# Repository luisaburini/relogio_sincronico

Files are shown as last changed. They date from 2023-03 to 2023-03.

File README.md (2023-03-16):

# Relógio Sincrônico

Instruções para montagem do trabalho de arte "Relógio Sincrônico" da artista Isadora Maia, que esteve na exposição "Mesmo Estando Separados" com a curadoria de Bruna Fernanda, Caio Bonifácio, Érica Burini, Glauce Santos e Lucas Goulart, no Ateliê 397, que fica na Rua Cruzeiro, 802, Barra Funda. 

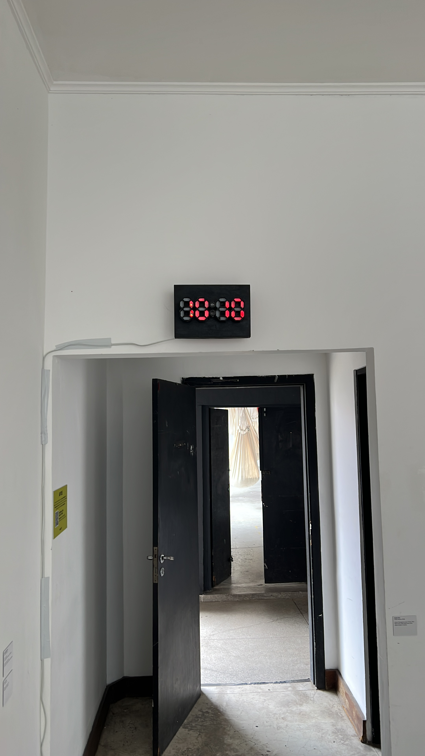
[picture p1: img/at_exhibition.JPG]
At exhibition

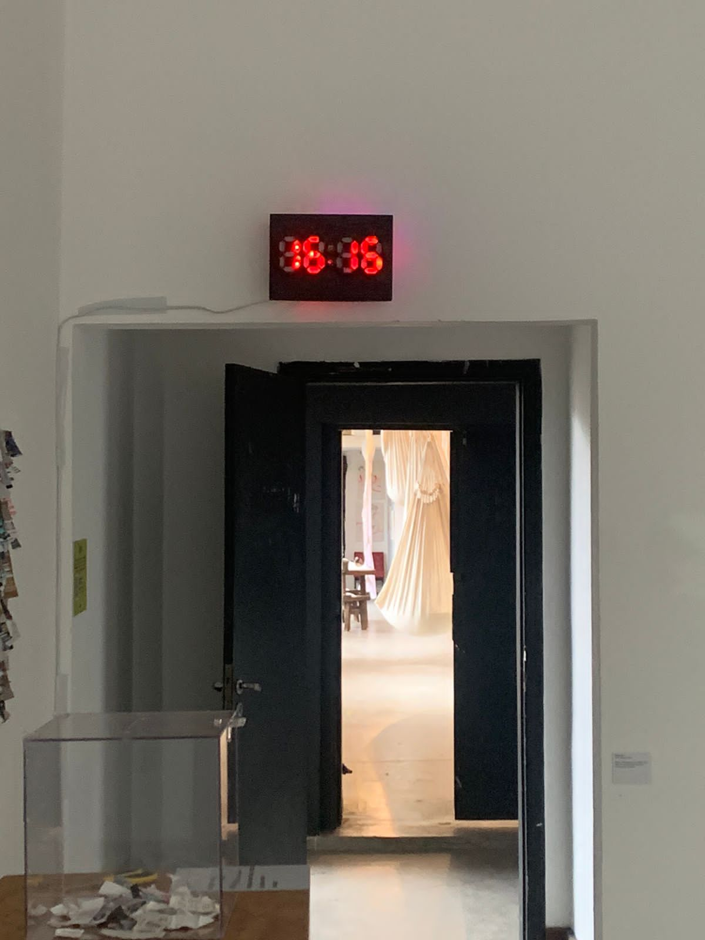
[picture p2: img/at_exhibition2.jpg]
At exhibition


## Materiais

- Arduino UNO R3 ATMEGA328p
- Módulo Real Time Clock DS3231
- Bateria de Lítio Recarregável LI2032 3,6V
- 5 mini protoboards 170 furos
- Jumpers (macho-macho e macho-fêmea)
- Fonte 5V para Arduino
- 5m fita de LEDs WS2811 
- Ferro de solda e estanho 
- Fonte 12V para fita de LEDs
- Caixa de MDF (32x22x5 cm)
- Tinta Spray preto fosco
- Impressão 3D - 28 Difusores para Segmentos
- Impressão 3D - 2 Difusores para Pontos
- Impressão 3D - Traseira
- Impressão 3D - Frente
- Folha de Acetato A3 30x42 cm
- Velcro
- 2 mão francesa 
- Extensão Tripolar de 5m branca 

## Descrição

O trabalho de montagem consistiu em obter uma solução para montar um relógio que exibe a mesma informação ha hora no minuto.
Para concretizar esse relógio, foi usado um Arduino conectado ao módulo RTC para obter a hora, mapear cada dígito em um buffer do tamanho da fita de led que ilumine apenas os trechos que representem o número.
Para exibir os dígitos, foi usado um molde de impressão 3D que forme o desenho do display de 7 segmentos.
A caixa de MDF pintada com tinta spray encapsulou os demais materiais, em especial para esconder os jumpers, protoboard e mostrar as peças feitas por impressão 3D com a fita LED no interior. A folha de acetato e o velcro evitam que as peças internas tenham contato com a parede e, por fim, a mão francesa garante apoio na parede para pendurar.

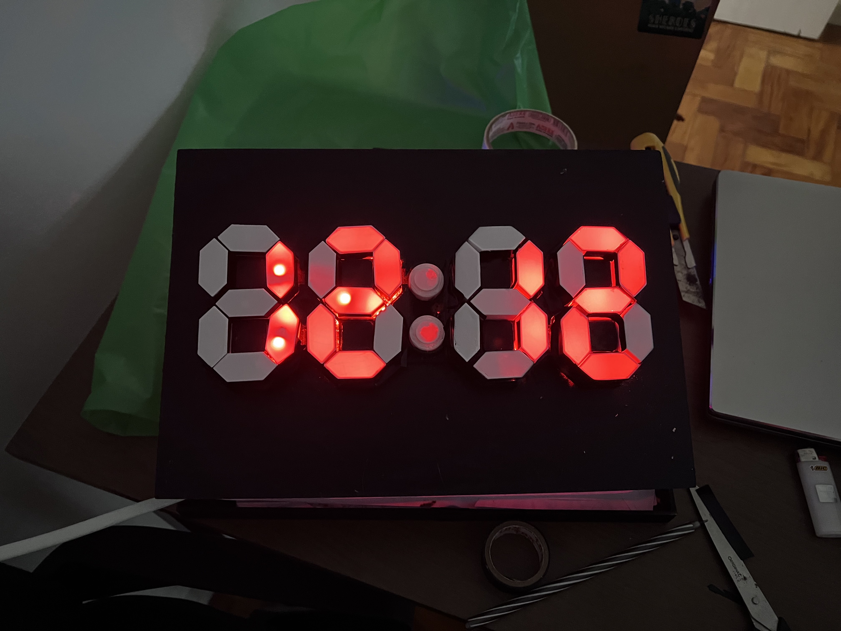
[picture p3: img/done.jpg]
Done!


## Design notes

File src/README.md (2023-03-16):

# Circuito 

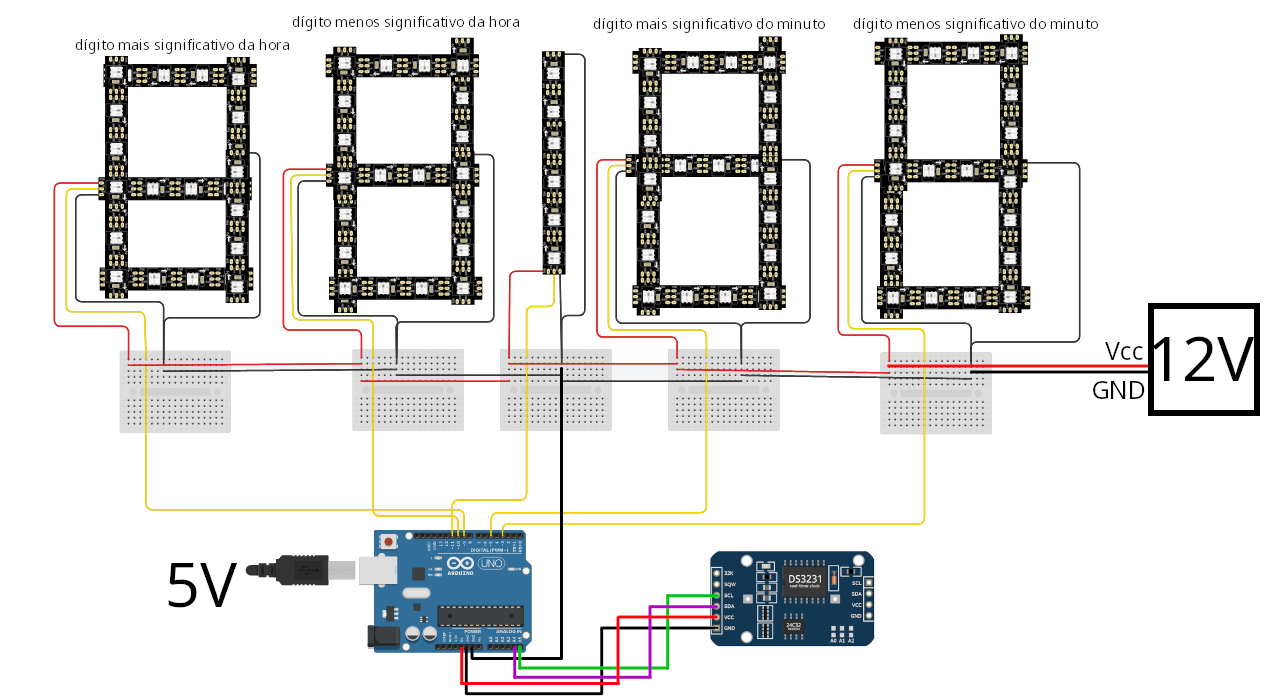
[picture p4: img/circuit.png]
Circuit

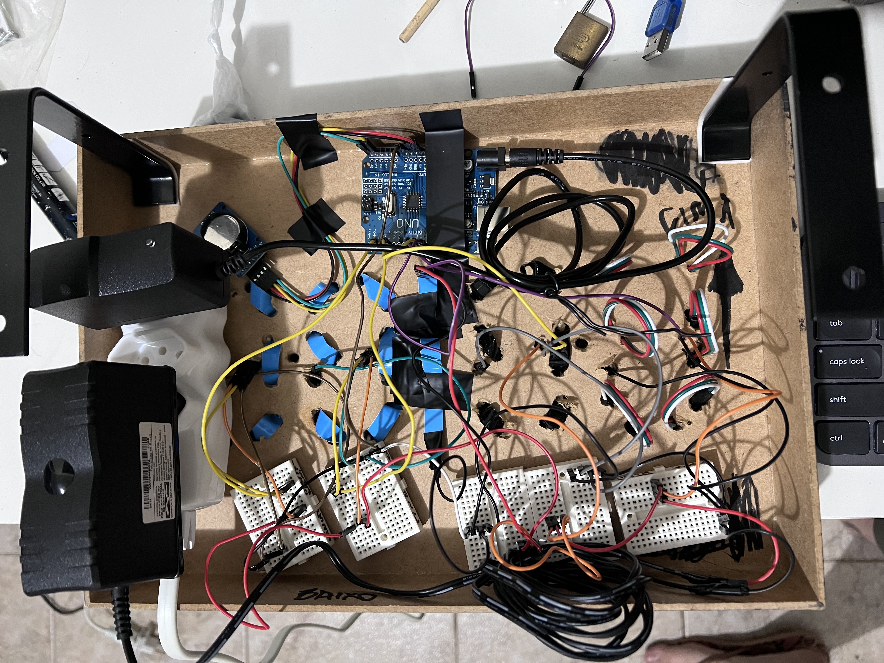
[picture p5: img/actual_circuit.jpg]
Actual Circuit


## RTC 

Foi utilizado o módulo DS3231, com a biblioteca [RTClib](https://adafruit.github.io/RTClib/html/class_r_t_c___d_s3231.html)

| Pino Arduino | Pino RTC |
|:---:|:---:|
| A5 | SCL |
| A4 | SDA |
| 5V | VCC |
| GND | GND |

*Atenção:* Foi utilizado 5V devido a bateria recarregável LI2032 3,6V. Se utilizar uma bateria CR2032 conecte em 3V!

OBS.: A bateria recarregável pode demorar até 2 dias para carregar o suficiente para salvar o dado da data/hora!

## Fita LED

Para conectar as fitas de LED ao Arduino, foi necessário soldar jumpers machos na emenda que garante contato. 

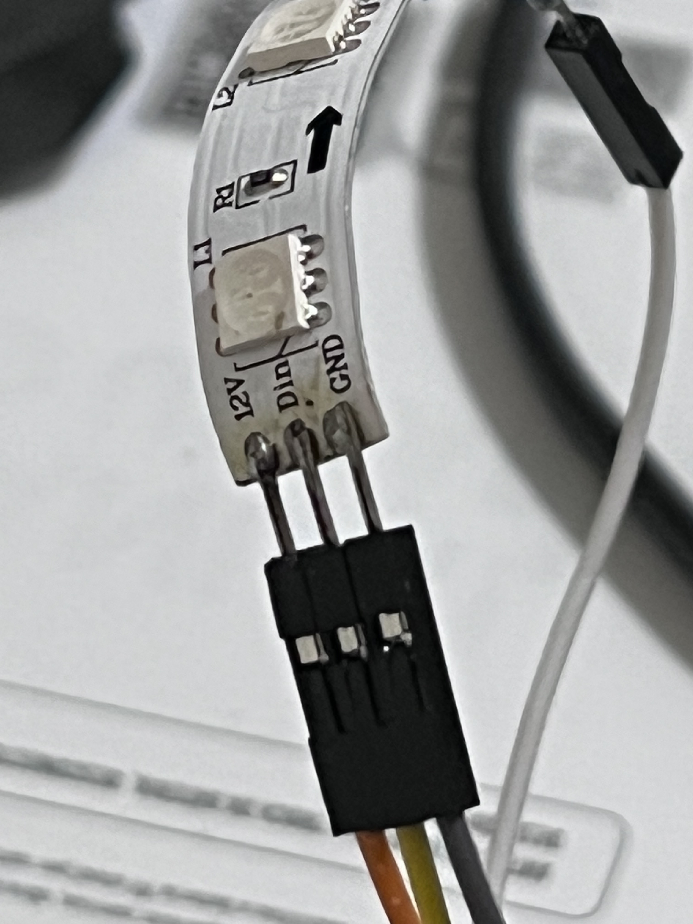
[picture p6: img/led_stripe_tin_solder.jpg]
Led Stripe Tin Solder


### Mapeamento dos dígitos 

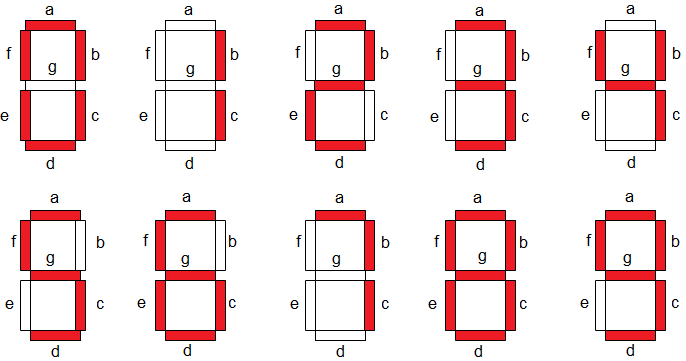
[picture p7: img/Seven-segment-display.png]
7 segmentos nomeados ABCDEFG


| | 0 | 1 | 2 | 3 | 4  | 5 | 6 | 7  | 8 | 9 |
|-----|:---:|:-----:|:-----:|:-----:|:----:|:-----:|:---:|:----:|:---:|:---:|
|  ON | ABCDEF | BC  | ABDEG | ABCDG | BCFG | ACDFG | ACDEFG |  ABC | ABCDEFG | ABCDFG |
| OFF | G | ADEFG | CF  | EF  |  ADE | BE  | B | DEFG | | E |

No nosso caso, cada segmento possui a menor unidade da fita, que são 3 LEDs em sequência.

*Atenção:* Se o segmento utilizado for muito grande, é possível que seja necessário um circuito auxiliar para que a corrente que chega aos pinos do Arduino seja compatível. Segundo o [datasheet](https://html.alldatasheet.com/html-pdf/1132633/WORLDSEMI/WS2811/2853/5/WS2811.html), cada LED irá puxar 18.5mA, no caso, 3 por segmento, em 7 segmentos: 21 LEDs, então, 388.5mA

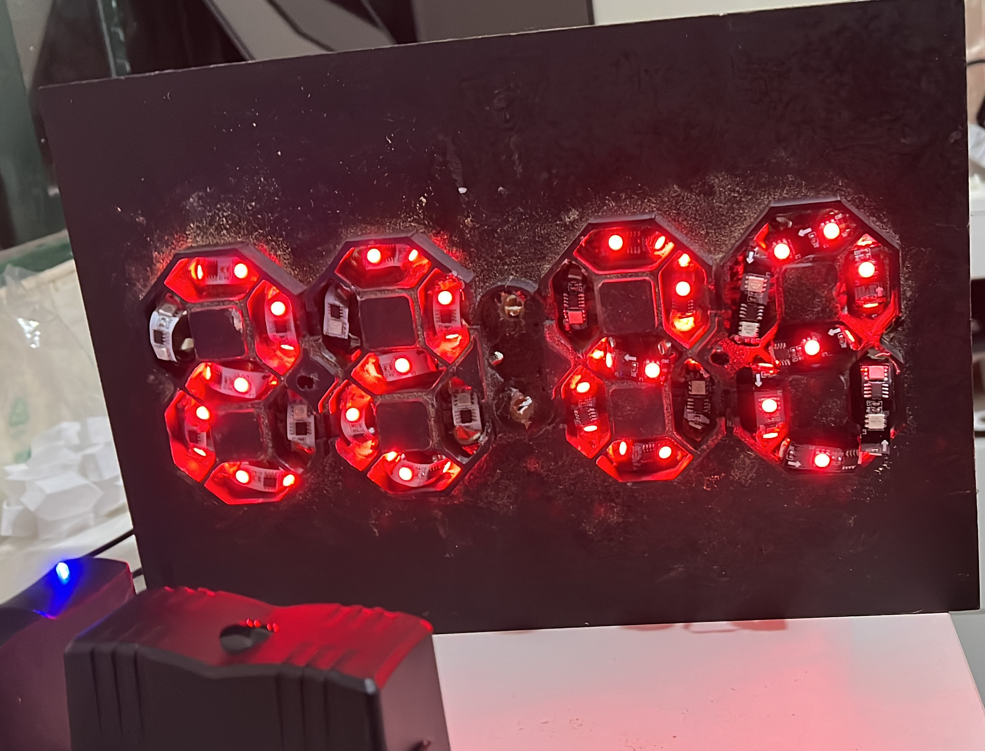
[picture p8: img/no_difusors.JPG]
No difusors


# Bilioteca

Para controlar os leds, foi utilizada a biblioteca [FastLED](https://github.com/FastLED/FastLED/wiki/Basic-usage)

| Pino Arduino | Fita LED |
|:---:|:---:|
| 9 | Din Mais Significativo Hora  |
| 10 |  Din Menos Significativo Hora  |
| 11 | Dois Pontos |
| 5 |  Din Mais Significativo Minuto |
| 3 | Din Menos Significativo Minuto |

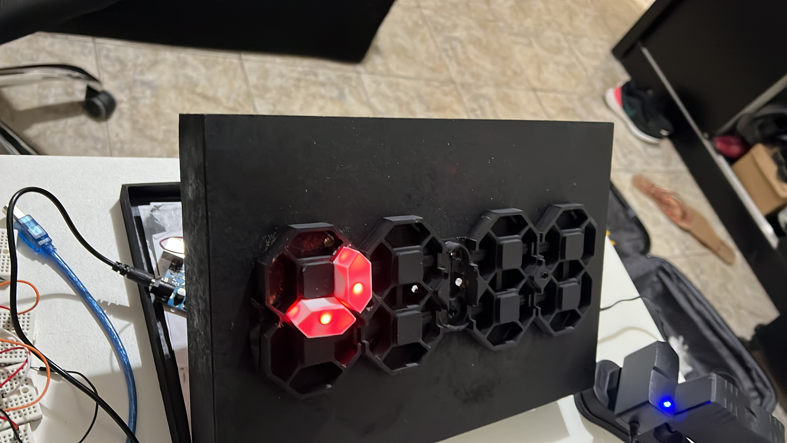
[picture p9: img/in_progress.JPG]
WIP


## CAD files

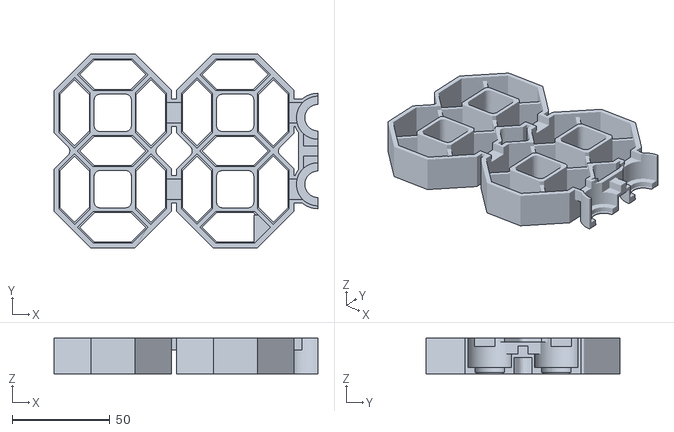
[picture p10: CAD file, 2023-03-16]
3d_printer/split_housing.stl
134.8 x 99.0 x 18.3

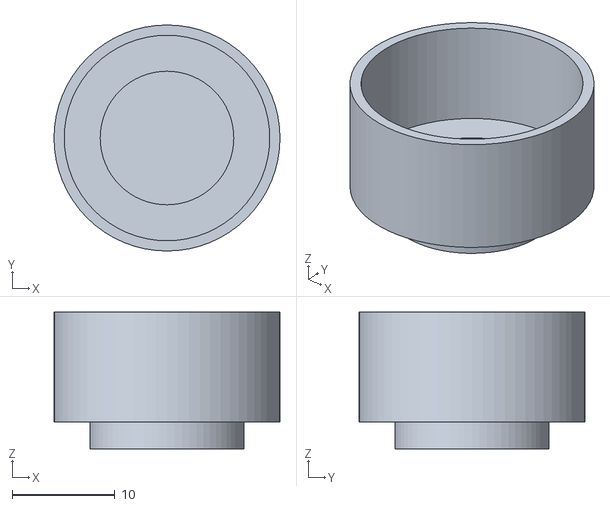
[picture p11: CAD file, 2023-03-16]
3d_printer/diffusor_round.stl
22.0 x 22.0 x 13.3

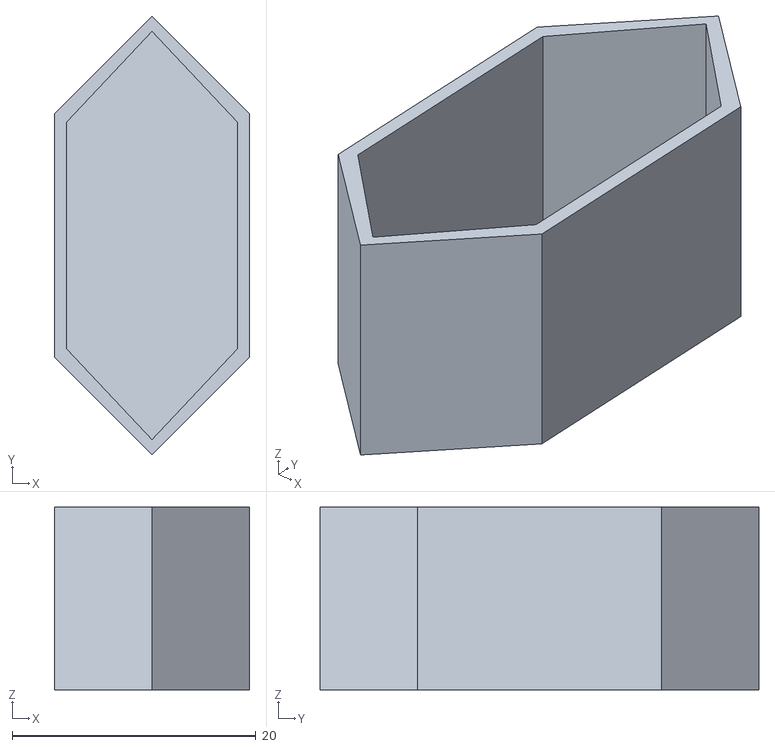
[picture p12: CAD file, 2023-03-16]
3d_printer/diffusor.stl
16.0 x 36.0 x 15.0

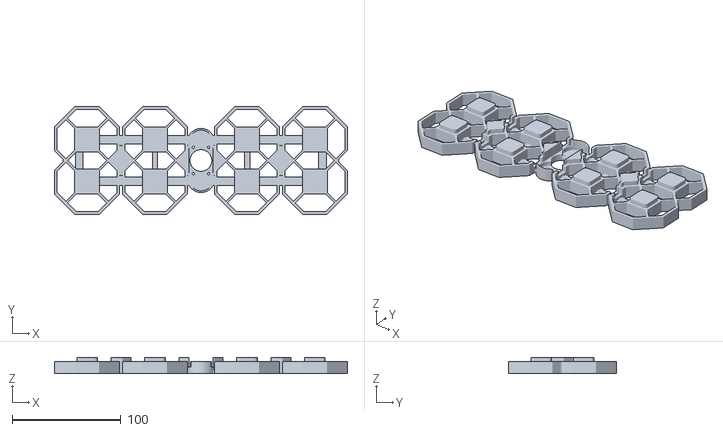
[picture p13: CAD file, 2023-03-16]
3d_printer/back_cover.stl
269.6 x 99.0 x 15.0

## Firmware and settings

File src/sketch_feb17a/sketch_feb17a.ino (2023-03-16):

#include <string.h>
#include <Wire.h>
/*
 * RTC SETUP
 */
#include <RTClib.h>

DS3231 rtc;

void initializeRTC()
{
  Serial.println("Initialize RTC");
#ifdef AVR
  Wire.begin();
#else
  Wire1.begin(); // Shield I2C pins connect to alt I2C bus on Arduino Due
#endif
  if(!rtc.begin())
  {
    Serial.println("RTC not initialized");
  }

  if (!rtc.isrunning()) {
    Serial.print("RTC will adjust to ");
    Serial.println(__TIME__);
    // following line sets the RTC to the date & time this sketch was compiled
    rtc.adjust(DateTime(__DATE__, __TIME__));
  }
}


/*
 * LEDS SETUP
 */

#include <FastLED.h>

#define PIN_MOST_SIGNIFICANT_HOUR_LEDS 9
#define PIN_LESS_SIGNIFICANT_HOUR_LEDS 10
#define PIN_TWO_POINTS_DATA_LEDS 11
#define PIN_MOST_SIGNIFICANT_MINUTE_LEDS 5
#define PIN_LESS_SIGNIFICANT_MINUTE_LEDS 3
#define NUM_PER_DIGIT 8
#define NUM_PER_TWO_POINTS 4
#define LED_TYPE NEOPIXEL
#define RED_MAX_VALUE 255

CRGB mostSignificantHourLeds[NUM_PER_DIGIT];
CRGB lessSignificantHourLeds[NUM_PER_DIGIT];
CRGB twoPointsLeds[NUM_PER_TWO_POINTS];
CRGB mostSignificantMinuteLeds[NUM_PER_DIGIT];
CRGB lessSignificantMinuteLeds[NUM_PER_DIGIT];

void initializeLEDs()
{
  delay(3000); // 3 second delay for recovery
  Serial.println("NEOPIXEL");

  FastLED.addLeds<LED_TYPE, PIN_MOST_SIGNIFICANT_HOUR_LEDS>(mostSignificantHourLeds, NUM_PER_DIGIT);
  FastLED.addLeds<LED_TYPE, PIN_LESS_SIGNIFICANT_HOUR_LEDS>(lessSignificantHourLeds, NUM_PER_DIGIT);
  FastLED.addLeds<LED_TYPE, PIN_TWO_POINTS_DATA_LEDS>(twoPointsLeds, NUM_PER_TWO_POINTS);
  FastLED.addLeds<LED_TYPE, PIN_MOST_SIGNIFICANT_MINUTE_LEDS>(mostSignificantMinuteLeds, NUM_PER_DIGIT);
  FastLED.addLeds<LED_TYPE, PIN_LESS_SIGNIFICANT_MINUTE_LEDS>(lessSignificantMinuteLeds, NUM_PER_DIGIT);

  FastLED.setBrightness(2);
}

void setup() {
  Serial.begin(9600);
  Serial.println("Starting execution");

  initializeRTC();

  initializeLEDs();
}


/*
 * RTC LOOP
 */
#define MOST_SIGNIFICANT_DIGIT 11
#define LESS_SIGNIFICANT_DIGIT 12

int getHourDigit(char* time, int digit)
{
  Serial.println("Get Hour Digit");
  char hourDigitStr[2];
  hourDigitStr[0] = time[digit];
  hourDigitStr[1] = '\0';
  int hourDigit = atoi(hourDigitStr);
  return hourDigit;
}

/*
 * LEDS LOOP
 */

bool isG(int i)
{
  return (i==0);
}
bool isB(int i)
{
  return (i==1);
}
bool isA(int i)
{
  return (i==2);
}
bool isF(int i)
{
  return (i==3);
}
bool isE(int i)
{
  return (i==4) ;
}
bool isD(int i)
{
  return (i==5);
}
bool isC(int i)
{
  return (i==6);
}

int redValueForZero(int i)
{
  // OFF: G
  if(isG(i))
  {
    return 0;
  }
  else // ON: ABCDEF
  {
    return RED_MAX_VALUE;
  }
}

int redValueForOne(int i)
{
  // OFF: ADEFG
  if(isA(i) || isD(i) || isE(i) || isF(i) || isG(i))
  {
    return 0;
  }
  else // ON: BC
  {
    return RED_MAX_VALUE;
  }
}

int redValueForTwo(int i)
{
  // OFF: CF
  if(isC(i) || isF(i))
  {
    return 0;
  }
  else // ON: ABDEG
  {
    return RED_MAX_VALUE;
  }
}

int redValueForThree(int i)
{
  // OFF: EF
  if(isE(i) || isF(i))
  {
    return 0;
  }
  else // ON: ABCDG
  {
    return RED_MAX_VALUE;
  }
}

int redValueForFour(int i)
{
  // OFF: ADE
  if(isA(i) || isD(i) || isE(i))
  {
    return 0;
  }
  else // ON: BCFG
  {
    return RED_MAX_VALUE;
  }
}

int redValueForFive(int i)
{
  // OFF: BE
  if(isB(i) || isE(i))
  {
    return 0;
  }
  else // ON: ACDFG
  {
    return RED_MAX_VALUE;
  }
}

int redValueForSix(int i)
{
  // OFF: B
  if(isB(i))
  {
    return 0;
  }
  else // ON: ACDEFG
  {
    return RED_MAX_VALUE;
  }
}

int redValueForSeven(int i)
{
  // OFF: DEFG
  if(isD(i) || isE(i) || isF(i) || isG(i))
  {
    return 0;
  }
  else // ON: ABC
  {
    return RED_MAX_VALUE;
  }
}

int redValueForEight(int i)
{
  // ON: ALL! ABCDEFG
  return RED_MAX_VALUE;
}

int redValueForNine(int i)
{
  // OFF: E
  if(isE(i))
  {
    return 0;
  }
  else // ON: ABCDFG
  {
    return RED_MAX_VALUE;
  }
}

int redValue(int i, int number)
{
  switch(number)
  {
    case 0:
    {
      return redValueForZero(i);
    }
    break;
    case 1:
    {
      return redValueForOne(i);
    }
    break;
    case 2:
    {
      return redValueForTwo(i);
    }
    break;
    case 3:
    {
      return redValueForThree(i);
    }
    break;
    case 4:
    {
      return redValueForFour(i);
    }
    break;
    case 5:
    {
      return redValueForFive(i);
    }
    break;
    case 6:
    {
      return redValueForSix(i);
    }
    break;
    case 7:
    {
      return redValueForSeven(i);
    }
    break;
    case 8:
    {
      return redValueForEight(i);
    }
    break;
    case 9:
    {
      return redValueForNine(i);
    }
    break;
    default:
      return 0;
  }
}

void sendTimeToLed(int mostSignificant, int lessSignificant)
{
  FastLED.clear();
  // MOST SIGNIFICANT
  for(int i=0; i<NUM_PER_DIGIT; i++)
  {
    int red = redValue(i, mostSignificant);
    //mostSignificantLeds[i] = CRGB(0, 200, 0);
    mostSignificantHourLeds[i] = CRGB(red, 0, 0);
    mostSignificantMinuteLeds[i] = CRGB(red, 0, 0);
    // Serial.print("mostSignificantLeds[");
    // Serial.print(i);
    // Serial.print("] = ");
    // Serial.println(red);
  }



  // LESS SIGNIFICANT
  for(int i=0; i<NUM_PER_DIGIT; i++)
  {
    int red = redValue(i, lessSignificant);
    //lessSignificantLeds[i] = CRGB(0, 200, 0);
    lessSignificantHourLeds[i] = CRGB(red, 0, 0);
    lessSignificantMinuteLeds[i] = CRGB(red, 0, 0);
    // Serial.print("lessSignificantLeds[");
    // Serial.print(i);
    // Serial.print("] = ");
    // Serial.println(red);
  }


  // TWO POINTS
  for(int i=0; i<NUM_PER_TWO_POINTS; i++)
  {
    //int red = lessSignificant%2 == 0 ? 200 : 0;
    //twoPointsLeds[i] = CRGB(0, red, 0);
    twoPointsLeds[i] = CRGB(RED_MAX_VALUE, 0, 0);
    // Serial.print("twoPointsLeds[");
    // Serial.print(i);
    // Serial.print("] = ");
    // Serial.println(red);
  }
  
  FastLED.show(100);
}


void loop() 
{ 

  Serial.println("\n=============RTC===============\n");
  Serial.println(__DATE__);
  Serial.println(__TIME__);
  DateTime now = rtc.now();
  char time[30];
  Serial.println(now.tostr(time));
  
  int mostSignificantDigit = getHourDigit(time, MOST_SIGNIFICANT_DIGIT);
  Serial.println(mostSignificantDigit);
  int lessSignificantDigit = getHourDigit(time, LESS_SIGNIFICANT_DIGIT);
  Serial.println(lessSignificantDigit);

  Serial.println("\n=============LED===============\n");
  sendTimeToLed(mostSignificantDigit,lessSignificantDigit);
  delay(100);
}
